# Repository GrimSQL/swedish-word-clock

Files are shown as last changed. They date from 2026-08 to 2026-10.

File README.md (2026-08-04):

# Swedish Word Clock Simulator

An interactive browser-based simulator for a Swedish word clock (QlockTwo-style), designed as a proof-of-concept before building the physical hardware.

**[Live Demo](https://grimsql.github.io/swedish-word-clock/)**

  

## How It Works

The clock displays the current time in Swedish using illuminated words on an 11×10 letter grid. Time is shown in 5-minute intervals with the prefix **KLOCKAN ÄR** ("the clock is"), and four corner dots indicate extra minutes within each interval.

### Swedish Time Logic

Swedish uses a "half-hour" system where times from `:25` onward reference the **next** hour:

| Time  | Display |
|---|---|
| 16:00 | KLOCKAN ÄR **FYRA** |
| 16:05 | **FEM ÖVER** FYRA |
| 16:10 | **TIO ÖVER** FYRA |
| 16:15 | **KVART ÖVER** FYRA |
| 16:20 | **TJUGO ÖVER** FYRA |
| 16:25 | **FEM I HALV** FEM |
| 16:30 | **HALV** FEM |
| 16:35 | **FEM ÖVER HALV** FEM |
| 16:40 | **TJUGO I** FEM |
| 16:45 | **KVART I** FEM |
| 16:50 | **TIO I** FEM |
| 16:55 | **FEM I** FEM |

### Grid Layout

<pre>
<b>K L O C K A N</b> V H <b>Ä R</b>         KLOCKAN ÄR
S <b>F E M</b> I S <b>T I O</b> N A         FEM(min) TIO(min)
<b>T J U G O</b> M I E S N D         TJUGO
<b>K V A R T</b> B <b>Ö V E R</b> G         KVART ÖVER
L <b>I</b> A H <b>H A L V</b> Ö T P         I HALV
<b>E T T</b> R <b>T V Å</b> L S N D         ETT TVÅ
<b>T R E</b> N <b>F Y R A</b> O S T         TRE FYRA
<b>F E M</b> B <b>S E X</b> O <b>S J U</b>         FEM(hour) SEX SJU
<b>Å T T A</b> M <b>N I O</b> D E K         ÅTTA NIO
<b>E L V A T O L V T I O</b>         ELVA TOLV TIO(hour)
</pre>

> `FEM` and `TIO` appear twice each — once as minute words (row 1) and once as hour words (rows 7/9). **Bold** = active letters, normal = filler.

### Corner Dots

Four LEDs in the corners show minutes within each 5-minute block, just like a real QlockTwo:

```
+0 min   ○ ○ ○ ○     (exactly on the 5-min mark)
+1 min   ● ○ ○ ○
+2 min   ● ● ○ ○
+3 min   ● ● ● ○
+4 min   ● ● ● ●
```

## Features

- **6 color themes** — Warm White, Arctic, Matrix, Sunset, Minimal, Rose Gold (saved to localStorage)
- **Time slider** — scrub through the full 24h day to verify every time
- **Direct time input** — type exact times like `16:25` for edge case testing
- **Live mode** — syncs to your system clock in real-time
- **Click to toggle** — click any letter to manually light/dim it (shown in red) for debugging
- **Keyboard shortcuts** — arrow keys (±1 min), `L` (toggle live), `Esc` (close docs)
- **Built-in docs** — click DOCS for full reference on layout, time logic, and hardware specs
- **Single file** — zero dependencies, works offline, just open `index.html`

## Physical Build — `johniak-sv/`

The physical clock is a Swedish remix of [johniak/word-clock](https://github.com/johniak/word-clock) using **this repo's exact 11×10 letter grid** — cross-checked against the simulator's `GRID_LETTERS` on every generation, so the printed front and the simulator can never diverge.

| Component | Details |
|---|---|
| Shell | 3D-printed, 187×179 mm, letters printed in place (AMS: black + transparent) |
| LEDs | 110× WS2812B — **74 LEDs/m strip**, 10 uncut rows of 11 (13.51 mm pitch) |
| Back plate  | 3D-printed: ESP32 bay, self-centring funnel wall hook, alignment pegs, cable channel |
| MCU | ESP32 DevKit v1 (WiFi/NTP), firmware = johniak's + Swedish patch |
| Power | 5V 3A |

Generator, print files (`PRINTA/`), firmware patch and full build guide: [`johniak-sv/README.md`](johniak-sv/README.md).

Earlier build tracks are removed from the tree but remain in git history.

## Credits

The Swedish time-to-word mapping logic is based on [machosallad/tidsram](https://github.com/machosallad/tidsram), the only dedicated Swedish word clock project on GitHub. The 11x10 grid layout was custom-designed for denser packing compared to tidsram's 12x12.

## License

MIT

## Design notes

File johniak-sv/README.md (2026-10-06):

# johniak-sv — svensk version av johniaks Word Clock

Svensk remix av [johniak/word-clock](https://github.com/johniak/word-clock)
(Makerworld: "Word Clock"). Behåller originalets fysiska gränssnitt exakt —
yttermått 187×179 mm, 13,51 mm cellpitch (= 74 LEDs/m-strip), samma serpentin-
LED-ordning — så att originalets monteringsmetod, elektronikbox och firmware-bas
fungerar rakt av. Bara bokstäverna, layouten och tidslogiken är svenska.

**Varför den här basen:** cellavstånd = LED-avstånd → **hela obrutna stripremsor
per rad** (lödning bara vid radslut, ~30 punkter). Bokstäverna fylls med
**transparent filament** (AMS, printed in place) — inga bryggor, riktiga
bokstavsformer, och prime tower ryms gott på en 256-bädd (plattan är 187 bred).

## Layout (11×10 = 110 celler — simulatorns exakta matris)

**Tecken för tecken identisk med simulatorn** (`index.html`), inga tillagda
utfyllnadsbokstäver. Generatorn läser simulatorns `GRID_LETTERS` vid varje
körning och vägrar bygga om en enda cell avviker.

```
K L O C K A N V H Ä R      KLOCKAN ÄR
S F E M I S T I O N A      FEM TIO (minuter)
T J U G O M I E S N D      TJUGO
K V A R T B Ö V E R G      KVART ÖVER
L I A H H A L V Ö T P      I HALV
E T T R T V Å L S N D      ETT TVÅ
T R E N F Y R A O S T      TRE FYRA
F E M B S E X O S J U      FEM SEX SJU
Å T T A M N I O D E K      ÅTTA NIO
E L V A T O L V T I O      ELVA TOLV TIO
```

Valideras dessutom vid varje generering: ordpositioner, alla 288
femminuterstider, läsordning (rad OCH kolumn inom rad), LED-kollisioner.

## Generera

```bash
npm install
node generate.js            # Arial (störst bokstäver). Byt: node generate.js C:\Windows\Fonts\<font>.ttf
```

Utdata:
| Fil | Vad | Filament |
|---|---|---|
| `out/topshell_sv_body.stl` | Front + cellgaller i ett (187×179×12) | SVART (opak) |
| `out/topshell_sv_letters.stl` | Bokstäverna, fyller fronten (2,5 mm djup) | **TRANSPARENT** |
| `out/backplate_sv.stl` | Bakplatta: 12,5 mm ram, ESP32-bay, tratt-krok | SVART |
| `out/backplate_sv_markers.stl` | Strip-markeringsband, 10 st i plattans stripyta | **VIT/kontrast** |
| `out/preview.svg` | Visuell kontroll av layouten | — |
| `out/topshell_walls.svg` | Skalets väggar bakifrån: kabelslitsar + stripurtag | — |
| `firmware/words_sv.h` | Genererad LED-tabell till firmware-patchen | — |

Ingen extern elektronikbox behövs. Bakplattans baksida har en **ram runt hela
kanten, 2 mm bred och 12,5 mm hög** — klockan hänger på den, och lådan den
bildar är elektronikutrymmet. Ramen är 2 mm bred med flit: M3-hålen sitter
4,3–7,7 mm in från kanten, så ett ~6 mm skruvhuvud når 3 mm in — en bredare ram
och huvudet hade inte gått ner bredvid.

I lådan finns **ESP32-bay** (skenor + ändstopp runt en 1,8 mm hög limplatta),
**tratt-krok** som fångar väggskruven själv, **genomföringshål** för LED-kablarna
vid LED 0, och **piggslitsar**: tre piggar på skalets gallerväggar går ner i
slitsarna så plattan självcentrerar — de fyra M3-skruvarna klämmer. Nertill i
ramen är en **13 mm öppning** för USB-C-kontakten (10,5 mm + marginal), full
ramhöjd så kabeln läggs rakt i. Layout: `out/backplate_layout.svg`.

Höjdbudgeten i lådan är knapp och värd att räkna på innan du printar:

| Från plattan | Vad |
|---|---|
| 1,8 mm | limplattans topp |
| 5,0 mm | kortets ovansida (vilar på metallburken/USB-kontakten) |
| 3,4 mm | USB-C-uttagets mitt — därför klarar kontaktens gjutning plattan |
| 6,6 mm | kortets undersida, dit skenorna (7,5 mm) håller det på plats |
| ~12,6 mm | stiftlistens spetsar, om kortet har lödda listar |

Ramen är 12,5 mm. Har ditt kort lödda stiftlistor som sticker ut 6 mm nålar de
alltså precis i väggen — klipp dem korta, eller höj `RIM_H`.

Skalet är i sin tur urfräst för kablaget — allt uppifrån, öppet mot plattan, så
den färdiglödda plattan kan läggas rakt ner utan att något behöver träs igenom:

| Urtag | Var | Mått | Till vad |
|---|---|---|---|
| Stripurtag | topp av **varje** kolumnvägg, en per rad | 11 × 2,2 mm | stripens PCB korsar väggen (LEDsen sitter i cellcentrum, PCB:n pluggar igen urtaget) |
| Kabelslits | de **två yttre** kolumnväggarna, en per rad, båda sidor | 8 × 6 mm | serpentinens 3 ledare (5V/GND/DATA) ut i sidokanalen |
| Matningsslits | vid **LED 0** | 10 × 8 mm | 5 ledare + krympslangsknölen, rakt mot genomföringshålet |

Sidokanalen mellan cellgallret och ytterväggen är 16,2 mm bred och 9,5 mm djup
hela vägen — där ligger looparna. Se `out/topshell_walls.svg`.

## Printa (Bambu Studio)

1. **Top Shell:** importera `topshell_sv_body.stl` + `topshell_sv_letters.stl`
   TILLSAMMANS (svara **Ja** på "single object with multiple parts"). Body →
   filament 1 (svart, opak). Letters → filament 2 (**transparent** PLA — inte vit!).
   Framsidan nedåt. 0.2 mm, inga stöd, brim. Prime tower får plats bredvid.
   > **Obs:** i slicern (uppifrån) läses bokstäverna **baklänges** — det är
   > meningen (samma som originalet). Fronten printas mot plåten, så underifrån/
   > framifrån blir de rättvända. Färgbytena sker bara i de nedersta 2,5 mm.
2. **Bakplatta:** importera `backplate_sv.stl` + `backplate_sv_markers.stl`
   TILLSAMMANS (single object with parts). Plattan → svart, markerings-delen →
   **vit/valfri kontrastfärg** — det blir tio band i första lagret som visar
   exakt var varje LED-rad ska klistras. **Strip-sidan (märkta) nedåt**,
   fickan/kuddarna uppåt. 0.2 mm, brim, inga stöd.
   Utan AMS: skippa marker-filen — banden blir då 0,2 mm försänkta spår istället.

## Montera

1. Klipp 74/m-strippen i **10 hela rader à 11 LEDs** (klipp INTE mellan LEDs i
   raden). Max 10 mm bred strip — piggslitsarna går 0,4 mm från stripkanterna.
2. Klistra raderna **exakt i de tio markerade banden** på plattans stripyta —
   ett band = en rads fotavtryck, inget mätande behövs. **LED 0 (data in) =
   raden närmast genomföringshålet, börja vid hålet**; den raden går bort från
   hålet, serpentin vidare rad för rad.
3. Löd 5V/GND/DIN mellan radsluten. Looparna hamnar utanför gridfältet: de går
   ut genom **kabelslitsen** i den yttre kolumnväggen (8 × 6 mm, en per rad på
   båda sidor) och ligger i sidokanalen mellan cellgallret och ytterväggen.
4. Löd matningen på LED 0 och dra den genom **matningsslitsen** (10 × 8 mm, den
   breda) och vidare ut genom **genomföringshålet** (12 × 10 mm) i plattan strax
   bredvid → till **ESP32-fickan** på baksidan. Där ryms 5 ledare plus knölen
   från krympslangen. 5V + GND till
   strömmen, DIN till GPIO enligt originalets wiring-guide (`docs/device_build.md`).
   ESP32:n läggs i bayen med **metallburken nedåt mot limplattan** och USB-C
   nedåt; superlim på burken. Skenorna tar sidorna, ändstoppet toppen.
5. **Stäng klockan:** lägg plattan på skalet — de tre **piggarna** (sitter
   fast på skalets gallerväggar, printas ihop med skalet) går ner i slitsarna
   (passar bara åt rätt håll) — och skruva **4× M3 självgängande** genom
   plattans hörnhål in i skalets **hörnpelare** (bossarna).
   > Skruvkanalerna i pelarna är **fyrkantiga med flit** (2,7 mm): M3-skruven
   > pressas/gängas rakt i och biter i de fyra plansidorna — fyrkantigt
   > spricker mindre än runt i print. Alternativ: superlimma plattan mot
   > väggtopparna — men först när ALLT är testat (LEDs + firmware); en limmad
   > klocka går inte att öppna för service.
   Strömsladden går från bayen mellan kabelstöden och ut genom ramens
   **USB-öppning** under klockans underkant — kortast möjliga, syns inte framifrån.
6. Häng upp: skruv/spik i väggen med huvudet ~3–4 mm ut. Håll klockan mot väggen ungefär rätt och dra nedåt — **tratt-kroken** fångar skruven, centrerar den själv och låser huvudet bakom läppen. Eller ställ den på bord.
7. Firmware: se [`firmware/PATCH.md`](firmware/PATCH.md).

## Köplista

| Del | Spec |
|---|---|
| WS2812B-strip | **74 LEDs/m**, 2 m (110 LEDs + marginal), 5V, max 10 mm bred |
| ESP32 | DevKit v1 (52 × 28,7 mm — bayen är måttad exakt för den) |
| Superlim | fäster ESP32:ns metallburk mot limplattan |
| Transparent PLA | till bokstäverna (AMS filament 2) |
| Svart PLA | skal + bakplatta |
| Ström | 5V 3A |
| M3 självgängande | 4 st 8–10 mm (bakplatta → skalets bossar) |
| Väggskruv/spik | 1 st, huvud ≤ 9 mm, ~3–4 mm från väggen (tratt-kroken) |

## Äldre byggvarianter

Tidigare byggspår är borttagna ur trädet men finns kvar i git-historiken
(commiten före städningen).

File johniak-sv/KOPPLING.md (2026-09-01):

# Koppling — svensk ordklocka

Praktisk kopplingsplan från oklippt stripprulle till färdig klocka på väggen.
Läs [`README.md`](README.md) för mått och printning, den här filen för elen.

> **Allt som står "vänster" och "höger" i den här filen är sett FRAMIFRÅN**, med
> klockan rättvänd. Bakplattans **stripsida vänder framåt** mot bokstäverna, så
> när du lödar strippen ser du samma bild som någon framför klockan — ingen
> spegling. Först när du vänder plattan för att montera ESP32:n kastas vänster
> och höger om.
>
> Enda entydiga referensen när plattan ligger lös: **USB-C-öppningen i ramen
> sitter i klockans underkant.** Hittar du den vet du var nedan är.

> **Skalet har elva radplatser, men bara tio bär strip.** Den tomma sitter
> **överst**, ovanför KLOCKAN ÄR. Räkna därför aldrig fysiska rader uppifrån —
> utgå från bokstäverna, annars ligger du konsekvent ett steg fel.

---

## Status: vad som redan är gjort

ESP32:n är flashad och konfigurerad. Du behöver inte röra firmware för att koppla.

| | |
|---|---|
| Kort | ESP32-D0WD-V3 rev 3.1, 4 MB flash, MAC `d4:e9:f4:b2:74:20` |
| Firmware | WLED 16.0.1 "Niji" |
| Adress | `192.168.30.17` · `http://ordklocka.local` (fast IP satt i UniFi) |
| Namn | `Ordklockan` |
| LEDs | 110 st, typ WS281x, **GPIO16** |
| Matris | 11 × 10, serpentin, första LED **nere till vänster** |
| Strömgräns | 2000 mA |

Firmware uppdateras härifrån **över OTA** — klockan behöver aldrig mer kopplas
till USB för flashning.

---

## Kopplingsschema

```mermaid
graph LR
    PSU["5V 3A<br/>USB-C-laddare"] -->|USB-C| ESP["ESP32 DevKit v1<br/>i bakplattans bay"]
    ESP -->|"5V"| S5["strip +5V<br/>(röd)"]
    ESP -->|"GND"| SG["strip GND<br/>(vit)"]
    ESP -->|"GPIO16 → 330 Ω"| SD["strip DIN<br/>(grön)"]
```

### Strippens tre kablar → ESP32

**Färgen på pigtailen säger vad kabeln är. Texten på kortet säger vart den ska.**

| Strippens kabel | Signal | ESP32-stift | Står på kortet som |
|---|---|---|---|
| **Röd** | `+5V` | `VIN` | `VIN`, ibland `5V` |
| **Vit** | `GND` | `GND` | ta den **bredvid `VIN`** |
| **Grön** | `DIN` | GPIO16 | **`RX2`**, `D16` eller `16` — alla är samma stift |

Håll kortet med **USB-kontakten nedåt** och komponentsidan mot dig:

- **`VIN`** — nedersta stiftet i **vänstra** raden, hörnet närmast USB
- **`GND`** — direkt **ovanför** `VIN`, samma rad
- **`RX2`** — **högra** raden, **femte stiftet räknat nedifrån**

Röd och vit hamnar alltså bredvid varandra nere till vänster, grön ensam på
andra sidan kortet.

> ⚠️ **Kolla att röd sitter på `VIN` och inte på `RX2` innan du sätter i USB:n.**
> Det är den enda felkopplingen i hela bygget som kan skada kortet — 5 V rakt in
> i en 3,3 V-pinne. Att röd och grön hamnar på var sin sida av kortet är just
> för att göra förväxlingen svår.

Osäker på ditt kort? Mät `VIN` mot `GND` med USB i, ratten på `V⎓`: **4,6–5,0 V**
förväntat. Läser den 0 matar inte det kortet 5 V utåt, och strippens röda får tas
direkt från USB-källan istället.

`GPIO16` är silkscreen-märkt `RX2` på de flesta DevKit v1 — det ser ut som en
seriell port men är rätt stift. Det är satt i WLED under *Config → LED
Preferences*.

### Strippens kabelgrupper

Strippen har två kabelgrupper i samma ände och de sitter parallellt på samma tre
lödöar: en 3-grupp (röd/grön/vit = 5V/DIN/GND) och ett lösare par (röd/vit =
5V/GND för strömmatning). **De 3 är inte RGB** — WS2812B är adresserbar och
styrs av en enda dataledare.

### Verifiera innan du lödar

1. Titta på silkscreen där kablarna sitter: öarna är märkta `+5V`, `DIN`/`DO`, `GND`
2. Kolla pilarna på strippen — **ingångsänden är den pilarna pekar bort ifrån**
3. Den änden ska bli LED 0, alltså raden vid genomföringshålet

---

## LED-ordningen

Serpentin, 10 rader à 11 LEDs. Nedan sett framifrån, rad 1 överst.

| Rad | Bokstäver | LED | Riktning | Skarv till nästa rad |
|---|---|---|---|---|
| 1 | `K L O C K A N V H Ä R` | 99 → 109 | ← höger till vänster | — (sista) |
| 2 | `S F E M I S T I O N A` | 88 → 98 | → vänster till höger | **höger** kant |
| 3 | `T J U G O M I E S N D` | 77 → 87 | ← höger till vänster | **vänster** kant |
| 4 | `K V A R T B Ö V E R G` | 66 → 76 | → vänster till höger | **höger** kant |
| 5 | `L I A H H A L V Ö T P` | 55 → 65 | ← höger till vänster | **vänster** kant |
| 6 | `E T T R T V Å L S N D` | 44 → 54 | → vänster till höger | **höger** kant |
| 7 | `T R E N F Y R A O S T` | 33 → 43 | ← höger till vänster | **vänster** kant |
| 8 | `F E M B S E X O S J U` | 22 → 32 | → vänster till höger | **höger** kant |
| 9 | `Å T T A M N I O D E K` | 11 → 21 | ← höger till vänster | **vänster** kant |
| 10 | `E L V A T O L V T I O` | **0** → 10 | → vänster till höger | **höger** kant |

**Data börjar nederst till vänster** (LED 0 = `E` i ELVA) och slutar överst till
vänster (LED 109 = `K` i KLOCKAN). Nio skarvar totalt: fem på höger kant, fyra
på vänster.

> Källa: `ledIndex()` i [`generate.js:153`](generate.js). Kommentaren på rad 150
> säger "index 0 = bottom-right" — den är ärvd från johniaks 11-radersoriginal
> och stämmer inte här. Med 10 rader blir pariteten omvänd: rad 9 är udda, så
> `index = x` och LED 0 hamnar i kolumn 0. Rad 505 har det rätt.

### Varannan rad roteras 180°

Det här är det lättaste att göra fel. Varje klippt rad har en DIN-ände och en
DOUT-ände, och pilen visar riktningen. Rader som går vänster→höger (10, 8, 6, 4,
2) läggs med pilen åt höger. Rader som går höger→vänster (9, 7, 5, 3, 1) läggs
med pilen åt vänster — alltså **roterade ett halvt varv i planet**.

Rotera i planet, vänd inte på strippen. LEDsen ska fortfarande peka framåt.

> ⚠️ **Att pilarna pekar åt olika håll är RÄTT, inte fel.** Grannrader ska alltid
> peka åt var sitt håll — det är själva serpentinen. Ser du "flera lister åt fel
> håll" är det nästan alltid det här mönstret du tittar på, och då är allt som
> det ska.

| Pilen pekar | Rader |
|---|---|
| **åt höger →** | 10, 8, 6, 4, 2 |
| **åt vänster ←** | 9, 7, 5, 3, 1 |

Ögat är ändå inte facit här. **Stapel-testet är det**: släck allt, tänd den
vänstra LEDen i varje lödd rad (`99`, `88`, `77`, `66`, `55` …) i var sin färg.
De ska bilda en lodrät linje i vänsterkanten. Hoppar en av dem över till
högerkanten ligger just den raden bakvänd — och bara den.

En rad som klarat stapel-testet är bevisad rätt oavsett hur pilen ser ut för
ögat. Löd aldrig om en verifierad rad på en känsla.

---

## Steg för steg

> **Steg 1–2 är redan gjorda** — raderna är klippta och uppklistrade. Markerings-
> banden kom ut något förskjutna i printen; raderna är utmätta och placerade för
> hand istället och sitter rätt. Nästa sak att göra är att kontrollera
> pilriktningen (se nedan) och sen löda.

### 0. Testa hela rullen INNAN du klipper

Oklippt rulle = 148 LEDs. Koppla den provisoriskt med jumperkablar (5V, GND,
GPIO16) och kör igenom den. Hittar du en död LED nu är det en reklamation —
hittar du den efter 30 lödpunkter är det ditt problem.

> ⚠️ **Max 20 % ljusstyrka.** 148 LEDs på full vit drar 8,9 A. USB:n browner ut,
> kortet bootloopar, och det ser ut som trasig hårdvara.

### 1. Klipp 10 rader à 11 LEDs

Klipp **mitt i lödöarna mellan LEDs**, aldrig inne i en LED. Klipp inte inuti en
rad — varje rad ska vara 11 obrutna LEDs.

### 2. Klistra i markeringsbanden

Ett band = en rads fotavtryck, inget mätande behövs. Börja med rad 10 (`ELVA…`)
vid genomföringshålet. Kontrollera pilriktningen mot tabellen ovan **innan** du
trycker fast — 3M-tejpen släpper ogärna snyggt.

Lägg en klick smältlim i varje radände som avlastning. Stripens egen tejp
släpper från PLA efter ett par år i värme.

### 3. Löd de nio skarvarna

Tre ledare per skarv: `5V`, `GND`, `DO → DIN`. Loopen går ut genom
**kabelslitsen** (8 × 6 mm) i den yttre kolumnväggen och ligger i sidokanalen
mellan cellgallret och ytterväggen (16,2 mm bred, 9,5 mm djup).

- 24 AWG silikonkabel, ~6 cm per ledare
- Förtenna både ö och tråd, sen bara nudda ihop
- Krympslang över varje skarv
- Blyfritt: 350–370 °C, flussmedel är obligatoriskt, fogen blir matt och kornig — det är normalt

#### Skarvschemat

Kanten växlar varje gång. Datan går nedifrån och upp, så skarv 1 är den nedersta.

| Skarv | Från → till | Kant | Testa efter, 2D-index | Tända LEDs |
|---|---|---|---|---|
| 1 | rad 10 → 9 | **höger** | `[88,110,"FFFFFF"]` | 22 |
| 2 | rad 9 → 8 | **vänster** | `[77,110,"FFFFFF"]` | 33 |
| 3 | rad 8 → 7 | **höger** | `[66,110,"FFFFFF"]` | 44 |
| 4 | rad 7 → 6 | **vänster** | `[55,110,"FFFFFF"]` | 55 |
| 5 | rad 6 → 5 | **höger** | `[44,110,"FFFFFF"]` | 66 |
| 6 | rad 5 → 4 | **vänster** | `[33,110,"FFFFFF"]` | 77 |
| 7 | rad 4 → 3 | **höger** | `[22,110,"FFFFFF"]` | 88 |
| 8 | rad 3 → 2 | **vänster** | `[11,110,"FFFFFF"]` | 99 |
| 9 | rad 2 → 1 | **höger** | `[0,110,"FFFFFF"]` | 110 |

Fem på höger kant, fyra på vänster. Varje rad ligger vänd 180° mot sin granne, så
vid varje skarv gäller: **ström korsar diagonalt, data rakt över mitten.** Mitten-
ön är data på båda raderna och är den enda som inte byter sida vid rotationen.

#### Kolla riktningen på varje ny rad

Att raden lyser räcker inte — den kan lysa och ändå ligga bakvänd. Släck allt och
tänd den vänstra LEDen i varje lödd rad, en färg per rad:

```powershell
wled '{"on":true,"bri":128,"seg":[{"id":0,"fx":0,"frz":false,"col":[[0,0,0]]}]}'
wled '{"seg":[{"i":[99,"FF0000"]}]}'
wled '{"seg":[{"i":[88,"0000FF"]}]}'
wled '{"seg":[{"i":[77,"00FF00"]}]}'
```

De ska bilda en **lodrät linje i vänsterkanten**, en per rad nedifrån och upp.
Hoppar en av dem över till högerkanten ligger den raden 180° fel — och då ska
tejpen lossna nu, inte efter nästa skarv. Fortsätt med nästa index ur tabellen
(`66`, `55`, `44` …) allteftersom du lödar uppåt.

#### Mät varje skarv innan du sätter ström

Trettio sekunder med multimeter per skarv. Det är skillnaden mellan att **veta**
vilken fog som är trasig och att gissa i en färdiglödd loop.

Svart mätsladd i `COM`, röd i `VΩmA` — aldrig i `10A`-hålet, då kortsluter du det
du mäter så fort du går över till spänningsläge.

**Kontrollera mätaren på sig själv först:** nudda ihop de två metallspetsarna, den
ska pipa. Utan det vet du inte om "inget pip" betyder *ingen brygga* eller *fel
ratt-läge*.

**Grundregeln, och den enda du behöver minnas:**

| Du mäter | Pip betyder |
|---|---|
| **Längs samma ledare** — två ändar av samma tråd, eller `+5V`-ö till `+5V`-ö | ✅ Bra, strömmen kommer fram |
| **Mellan två olika ledare** — `+5V` mot `GND`, data mot `+5V` | ❌ Brygga |

Två avläsningsfällor: **`1` eller `OL` ensamt** längst till vänster betyder *över
mätområdet*, alltså **ingen** förbindelse — inte 1 ohm. Och ett **tal utan pip**
(t.ex. 718 Ω) mellan data och `GND` är LEDens inbyggda skydd, helt normalt. Det
är pipet som betyder brygga.

**1. Kortslutning mellan `+5V` och `GND`.** USB **ur** kortet — resistansmätning
på en strömsatt krets ger skräpvärden och kan skada mätaren. Ratten på `Ω` eller
kontinuitet ( ))) ). Proberna på `+5V`- och `GND`-ön i den nylödda radens ände.

| Du ser | Betyder |
|---|---|
| Några hundra Ω till flera kΩ, siffran **kryper uppåt** | Bra — LEDsens kondensatorer laddas av mätarens testström |
| Kort pip som tystnar | Samma sak. Normalt |
| **0–2 Ω, eller pip som inte slutar** | Brygga. Ta bort med avlödningsflätan och mät om innan ström |

**2. Att skarven sitter ihop.** Fortfarande strömlöst, kontinuitetsläge. Mät
tvärs över skarven, ö till ö: `DO → DIN`, `+5V → +5V`, `GND → GND`. Alla tre ska
pipa. Piper det inte är fogen kall — det felet kostar annars tio minuters
felsökning efter att du satt på strömmen.

**3. Spänningen från `VIN`.** Nu med USB i. Ratten på `V⎓` (DCV, inte vågen).
Svart på `GND`, röd på `VIN`. Förväntat **4,6–5,0 V**. Läser den 0 matar inte det
kortet 5 V utåt, och strippens röda får tas direkt från USB-källan istället.

Rutinen för resten av bygget: **löd skarv → mät 1 → mät 2 → USB i → tänd.**

### 4. Matningen på LED 0

Löd 5V, GND och DIN på LED 0:s öar (eller behåll fabrikskontakten om du klippt
så att ingångsänden hamnar där — då är den redan gjord). Sätt **330 Ω i serie på
DIN här**, inte vid ESP32:n.

Dra kabeln genom **matningsslitsen** (10 × 8 mm, den breda) och vidare ut genom
**genomföringshålet** (12 × 10 mm) i plattan → till ESP32-fickan på baksidan.

### 5. Testa alla 110 — innan något skruvas ihop

Koppla till ESP32:n med jumperkablar, stiften fortfarande hela. Kör
testkommandona nedan. Det här är sista tillfället att komma åt allt.

**Testa en rad i taget, inte allt på slutet.** Löd en skarv, tänd allt som är
lött, gå vidare. Startindex ur tabellen i [Testkommandon](#index-per-rad).
Tumregeln: lyser allt utom från skarv N och uppåt sitter felet i skarv N, och
ingen annanstans. Nio skarvar, nio tester — det är billigare än att leta i en
färdiglödd loop.

### 6. Löd fast på ESP32

Först nu, när testet är grönt:

1. Klipp stiften till **2–3 mm stubbar** (alla, inte bara de tre — resten nålar annars i väggen). Skyddsglasögon, de flyger
2. Löd kablarna på stubbarna
3. Klick smältlim som dragavlastning

Höjdbudgeten: ramen är 12,5 mm och ohyvlade stift når 12,6 mm. Dupont-hus ovanpå
är omöjliga — de skulle hålla klockan ut från väggen. Vill du ha en kontakt:
löd 3 cm pigtails på kortet och sätt en **JST-SM 3-pol wire-to-wire** liggande
platt i lådan (~6 mm tjock), eller höj `RIM_H` i [`generate.js:219`](generate.js) och printa om.

### 7. Montera

1. ESP32 i bayen, **metallburken ner** mot limplattan, USB-C nedåt. Superlim på burken
2. Lägg plattan på skalet — de tre piggarna går ner i slitsarna, passar bara åt rätt håll
3. 4× M3 självgängande genom hörnhålen in i skalets bossar
4. Strömsladden mellan kabelstöden och ut genom ramens USB-öppning
5. Häng på tratt-kroken: skruv i väggen med huvudet 3–4 mm ut, håll klockan mot väggen och dra nedåt

---

## Testkommandon

> ⚠️ **`i` räknar i matrisens läsordning, inte i datakedjan.** WLED körs i 2D-läge
> (11 × 10), och där är index **0 = övre vänstra hörnet** (`K` i KLOCKAN). Fysisk
> LED 0 — `E` i ELVA, nere till vänster — är alltså **2D-index 99**.
>
> `i` måste dessutom skickas **ensamt i sitt eget anrop**. Skickar du `col` eller
> `frz` i samma request händer ingenting synligt: segmentet fryser med föregående
> bild kvar och `i` faller bort. Sätt bakgrunden i ett anrop, tänd i nästa.
>
> Verifierat mot enheten 2026-08-30, under lödningen av rad 10.

### Index per rad

Startindex sjunker med 11 för varje rad du lödar på. Stopp är alltid 110.

| Rader lödda | Fysiska LEDs | Tänd 2D-index |
|---|---|---|
| 1 (`ELVA…`) | 0–10 | `[99,110,…]` |
| 2 (+ `ÅTTA…`) | 0–21 | `[88,110,…]` |
| 3 | 0–32 | `[77,110,…]` |
| 4 | 0–43 | `[66,110,…]` |
| 5 | 0–54 | `[55,110,…]` |
| 6 | 0–65 | `[44,110,…]` |
| 7 | 0–76 | `[33,110,…]` |
| 8 | 0–87 | `[22,110,…]` |
| 9 | 0–98 | `[11,110,…]` |
| 10 (allt) | 0–109 | `[0,110,…]` |

**start = 110 − 11 × antal rader.**

### PowerShell

`curl` är ett alias för `Invoke-WebRequest` i PowerShell, och PS 5.1 äter dessutom
citattecknen i JSON:en innan riktiga `curl.exe` hinner se dem. Definiera en
hjälpare istället — en gång per terminalfönster:

```powershell
function wled($json) { Invoke-RestMethod -Uri http://192.168.30.17/json/state -Method Post -ContentType 'application/json' -Body $json }
```

**Svart bakgrund** (ofryst) — kör alltid detta först, annars ligger gammal bild kvar:

```powershell
wled '{"on":true,"bri":128,"seg":[{"id":0,"fx":0,"frz":false,"col":[[0,0,0]]}]}'
```

**Tänd bara fysisk LED 0 rött** — ska lysa nere till vänster, `E` i ELVA:

```powershell
wled '{"seg":[{"i":[99,"FF0000"]}]}'
```

**Riktningstest** — ska växa åt höger, `E L V`:

```powershell
wled '{"seg":[{"i":[99,102,"FF0000"]}]}'
```

**Tänd alla lödda rader vitt** — leta mörka luckor. Byt 99 mot startindex ur
tabellen ovan allteftersom du lödar uppåt:

```powershell
wled '{"seg":[{"i":[99,110,"FFFFFF"]}]}'
```

**Tillbaka till normalt läge.** Individuell LED-styrning fryser segmentet — utan
det här kör inga effekter:

```powershell
wled '{"on":true,"bri":128,"seg":[{"id":0,"fx":0,"frz":false,"col":[[255,160,0]]}]}'
```

**Läs av kortets faktiska tillstånd** när något beter sig oväntat:

```powershell
Invoke-RestMethod http://192.168.30.17/json/state
```

**Släck:**

```powershell
wled '{"on":false}'
```

### bash / curl

Samma anrop, för den som sitter på en Linux-burk:

```bash
curl -X POST -H "Content-Type: application/json" -d '{"on":true,"bri":128,"seg":[{"id":0,"fx":0,"frz":false,"col":[[0,0,0]]}]}' http://192.168.30.17/json/state
```

```bash
curl -X POST -H "Content-Type: application/json" -d '{"seg":[{"i":[99,"FF0000"]}]}' http://192.168.30.17/json/state
```

```bash
curl -X POST -H "Content-Type: application/json" -d '{"seg":[{"i":[99,110,"FFFFFF"]}]}' http://192.168.30.17/json/state
```

```bash
curl -X POST -H "Content-Type: application/json" -d '{"on":true,"bri":128,"seg":[{"id":0,"fx":0,"frz":false,"col":[[255,160,0]]}]}' http://192.168.30.17/json/state
```

## Felsökning

| Symptom | Trolig orsak |
|---|---|
| Ingenting lyser alls | Ingen gemensam GND, eller DIN i fel ände av strippen (kolla pilarna) |
| `i`-kommandot gör ingenting, gammal bild ligger kvar | `i` skickades tillsammans med `col`/`frz`. Skicka det ensamt, i eget anrop |
| `i` tänder inget alls, oavsett index | Fel index — 2D-läge räknar i läsordning, fysisk LED 0 = index **99** |
| Allt svart och `{"on":true}` hjälper inte | Primärfärgen står på `[[0,0,0]]`. Sätt en riktig färg i `col` igen |
| Första LED lyser, resten mörka | Bruten dataledare i första skarven, eller DO/DIN förväxlade |
| Allt lyser men fel LEDs tänds | Rad lagd åt fel håll — jämför mot riktningskolumnen i tabellen |
| Hela bilden speglad | Fel `b`/`r` i WLED:s 2D-panel. Fixas i mjukvara, inte med lödkolven: *Config → 2D Configuration → First LED* |
| Slumpmässigt flimmer | 3,3 V data mot 5 V-strip. Testa kortare datakabel först, annars 74AHCT125 som nivåomvandlare |
| Kortet startar om vid hög ljusstyrka | Strömbrist. Kolla att gränsen är 2000 mA under *Config → LED Preferences* |
| Ojämn ljusstyrka över raderna | Spänningsfall. Bara relevant om du kör över 2 A — annars är 24 AWG gott och väl |

Orientering är alltid en mjukvaruinställning. Har du lödt rätt serpentin men
bilden hamnar fel — rör inte lödkolven, vänd `b`/`r`/`v` i 2D-konfigurationen.

---

## Vad som återstår efter det här

Standard-WLED visar **inte** svensk tid. Det du får nu är alla 110 LEDs,
2D-effekter och HA-integration. Klockfunktionen kräver den custom-byggda word
clock-usermoden — steg 3 i [`../TODO.md`](../TODO.md).

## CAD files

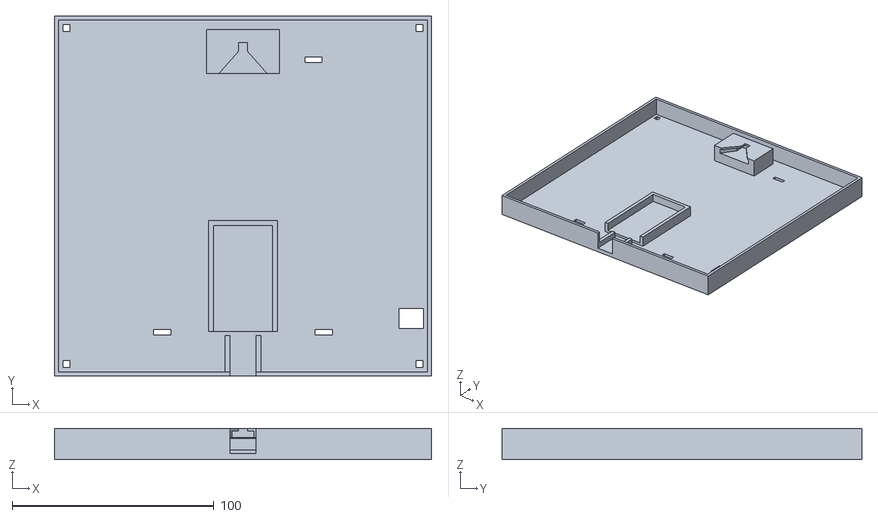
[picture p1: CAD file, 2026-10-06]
johniak-sv/PRINTA/3_bakplatta-SVART.stl
187.1 x 178.6 x 15.5

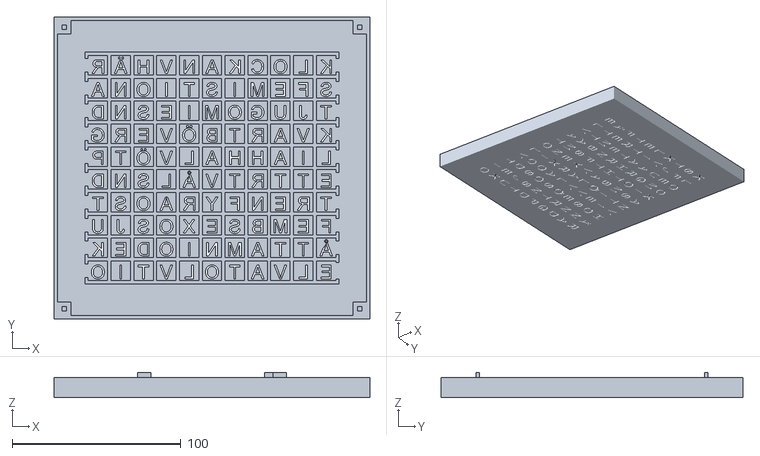
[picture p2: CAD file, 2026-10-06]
johniak-sv/PRINTA/1_topshell-SVART.stl
187.1 x 178.6 x 15.0

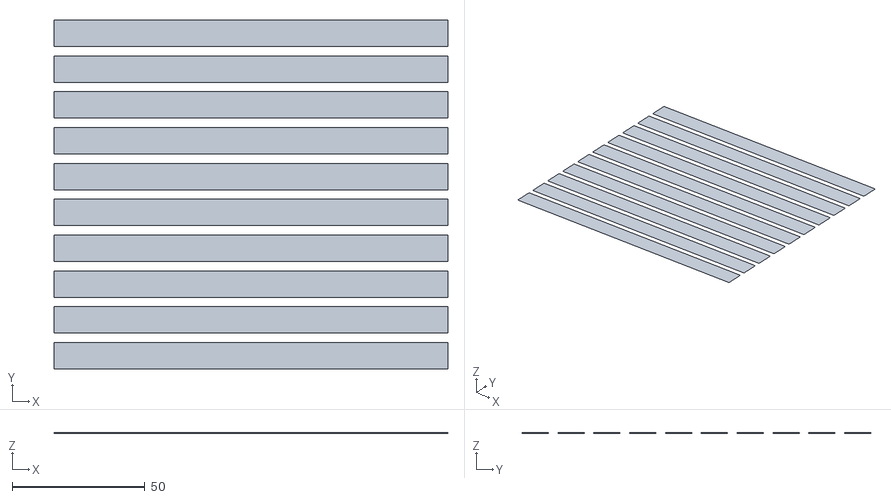
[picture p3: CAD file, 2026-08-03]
johniak-sv/PRINTA/4_bakplatta-markeringar-VIT.stl
148.6 x 131.6 x 0.2

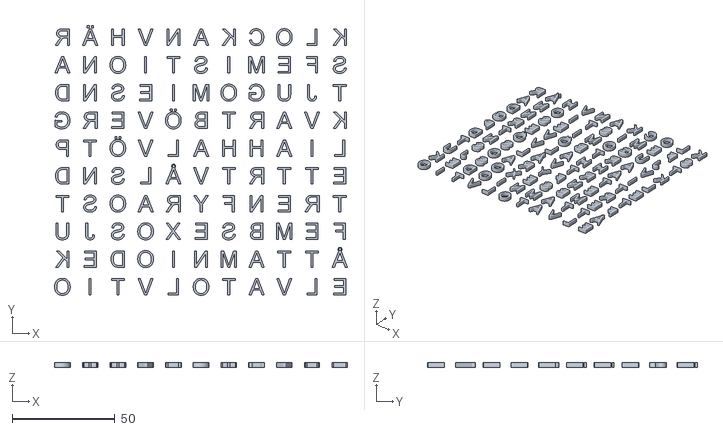
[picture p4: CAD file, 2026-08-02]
johniak-sv/PRINTA/2_topshell-bokstaver-TRANSPARENT.stl
142.8 x 131.4 x 2.50

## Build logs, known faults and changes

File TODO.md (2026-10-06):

# TODO — Svensk ordklocka

Ordningen är medveten: bygg grunden först, sen mjukvarulyxen. Från steg 2 och
framåt rörs aldrig hårdvaran igen — allt är firmware/HA (OTA efter första flashen).

**Status 2026-09-02: klockan hänger på väggen och visar svensk tid.** Steg 1, 3
och det mesta av 4–5 är klara. Kvar är automationerna och simulatorkortet.

## 1. Färdigställ bygget ✅
- [x] Top Shell printad (svart + transparenta bokstäver, AMS)
- [x] Bakplatta v2: piggslitsar fixade, stripband, ficka nere, tratt-krok
- [x] Printa om Top Shell (`johniak-sv/PRINTA/1_` + `2_`) — kabelslitsar per rad,
      bred matningsslits vid LED 0, stripurtag i kolumnväggarna
- [x] Printa om bakplattan (`johniak-sv/PRINTA/3_` + `4_`) — 12,5 mm ram,
      13 mm USB-C-öppning, ESP32-bay med limplatta och krok
- [x] Vänta in leverans: WS2812B 74/m 2 m + ESP32 DevKit v1
- [x] Klipp 10 rader à 11 LEDs, klistra i banden, löd serpentin
- [x] Testa alla 110 LEDs INNAN plattan skruvas fast
- [x] ESP32 i fickan, skruva M3 i hörnpelarna
- [x] Häng på tratt-kroken

> Nio skarvar, alla mätta och verifierade rad för rad. Rutinen och fällorna
> ligger i [`johniak-sv/KOPPLING.md`](johniak-sv/KOPPLING.md) — särskilt att ett
> kontinuitetspip inte räcker på strömledare (en fog på 80 Ω piper glatt och
> stryper ändå raden) och att pilarna ska växla varannan rad.

## 2. Firmware steg 1 — johniak + svensk patch ⏭️ ÖVERHOPPAT
Medvetet hoppat över. Kortet kom med WLED, och steg 3 hade ändå ersatt den här
firmwaren. [`PATCH.md`](johniak-sv/firmware/PATCH.md) sparas som referens —
tidslogiken där är samma som usermoden använder.

## 3. Firmware steg 2 — WLED med svensk word clock-usermod ✅
- [x] Custom-bygg av WLED 16.0.1 med egen usermod
- [x] Porta svenska ordtabellen till usermodens layout (rad/kolumn, inte LED-index)
- [x] Konfigurera 2D-matris 11×10, serpentin, första LED nere till vänster
- [x] Kuratera 17 presets — 5 klocklägen, 5 figurer, 7 helmatriseffekter
- [x] Figurlägen: hjärta, stjärna, gran, snöflinga, katt, blixt, utropstecken
- [x] Sifferdisplay — timer, temperatur och nedräkning är samma tvåsiffriga läge
- [x] `script.ordklockan_timer`, `script.ordklockan_visa_sensor` och
      automationen som håller talet färskt
- [x] Exponera aktuell fras och tänd-mask i `/json/info` för Home Assistant
- [x] OTA-flasha
- [x] NTP + tidszon CET/CEST med automatisk sommartid
- [x] Boot-preset `Klockläge` — klockan kommer tillbaka likadan efter strömavbrott
- [x] Lokal NTP-källa: NAS:en (`192.168.1.30`, DSM:s NTP-server). Krävde en ny
      brandväggsregel `AUTO IoT till NAS NTP` i GrimSQL/udm-firewall — UDM:en kör
      ingen egen NTP-server, verifierat med SNTP-probe mot alla tre VLAN

Källkod och byggguide: [`johniak-sv/firmware/wled-usermod/`](johniak-sv/firmware/wled-usermod/README.md).
Presets skapas om med [`johniak-sv/tools/presets.py`](johniak-sv/tools/presets.py).

## 4. Home Assistant-integration
- [x] WLED-integrationen → `light.ordklockan` + 17 entiteter till
- [x] `packages/ordklockan.yaml`: rest_command för klockläget, `sensor.ordklockan_text`
      (aktuell fras), `binary_sensor.ordklockan_klocklage`
- [x] `script.ordklockan_scen` — sätter preset OCH klockläge i ett anrop
- [x] `input_boolean.ordklockan_manuell` — manuell styrning vinner alltid över
      automationerna. Kortets knappar går via script som tänder flaggan;
      automationerna anropar tjänsterna direkt och rör den aldrig
- [x] Automation: släck när huset larmas **borta** (skalskydd undantaget — då är
      någon hemma). Nollställer också flaggan, så hemkomsten börjar rent
- [x] Automation: Lugn kväll efter solnedgången, Klockläge i dagsljus
- [x] Automation: släpp manuell styrning kl 04 som säkerhetsnät
- [x] Automation: rätta tiden om den glidit. WLED:s `Toki::millisecond()`
      räknade upp sekunder utan lås trots att den anropas från både
      Arduino-loopen och AsyncTCP-tasken — en tappad uppdatering flyttade
      klockan exakt 49 dygn 17:02:47 framåt, två gånger natten till 3 sep 2026.
      Firmwaren är patchad (`toki-threadsafe.patch`), automationen är nätet
      under: enheten NTP-synkar bara var 11,7:e timme
- [ ] Automationer kvar: larmblink (röd puls vid utlöst larm), hemkomst-puls,
      tvätt-klar. Alla tre vill ha en **figur** nu när klockan kan visa ❗ och ✓,
      inte bara en färg

## 5. Lovelace-dashboard
- [x] Effektväljare som knappgrid, scenknappar (Klockläge / Party / Lugn kväll / Natt),
      ljusstyrka, palett, hastighet — i `lampor`-vyn, Viktors button-card-stil
- [x] Simulatorn som live-kort — ritar firmwarens **egen** mask (`u.OrdklockanRutnat`,
      110 tecken i läsordning) via `sensor.ordklockan_rutnat`. Kortet duplicerar
      alltså ingen ordtabell i JavaScript och kan inte säga emot väggen
- [x] Kortet speglar väggens **faktiska pixlar** via `/json/live`
      (`sensor.ordklockan_pixlar`, 110 färger i attributet `leds`, en pollning
      per sekund). Masken räckte inte: den säger vad usermoden ritar, inte vad
      väggen lyser med. I läge `av` maskerar usermoden ingenting och publicerar
      en helt tänd mask — masken sa 110 tända celler medan Eld i verkligheten
      tände 53. Elva av sjutton presets kör en effekt och gick inte att återge
      med mask + en färg. Noteringen ovan om att kortet "inte kan säga emot
      väggen" gällde bokstäverna, inte ljuset
- [x] Knapparnas accentfärg följer väggens färg i stället för fast bärnsten,
      med läsbarhetsvakt för ljust tema
- [ ] Automations-togglar + ev. plats på floorplanen
- [ ] WLED:s webb-UI som iframe-flik för finlir

## Lösa trådar
- **330 Ω på datalinjen** är medvetet överhoppad. Klockan har gått felfritt utan
  den; är den första åtgärden om flimmer dyker upp.
- **`ordtest.py` mot `--all`** har aldrig körts hela varvet med plattan på.
  Värt att göra en gång för att se alla tolv femminutersblock.
- **WLED backar av 5 minuter** efter varje misslyckad NTP-uppslagning. Testa
  alltid NTP-ändringar med en omstart — annars mäter du backoffen och drar fel
  slutsats om nätverket.

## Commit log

2026-02-14 Initial release: Swedish word clock simulator
    Single-file HTML/JS simulator for a QlockTwo-style Swedish word clock.
    11x10 grid layout (110 LEDs + 4 corner dots), 6 color themes,
    time slider, live mode, and built-in documentation.
2026-02-14 Add laser cutting files: SVG generator, three grid sizes, stencil, separator and ordering guide
    Parametric Node.js generator produces laser-ready SVGs for the word clock front panel
    in S/M/L sizes, a stencil variant with Allerta Stencil font, and an egg-crate separator
    grid. Includes Swedish ordering guide with EU laser cutting services.
2026-02-14 Fix ÅÄÖ in README and add DXF export for Scandcut
    - Replace all ASCII approximations (AR→ÄR, OVER→ÖVER, TVA→TVÅ, ATTA→ÅTTA)
    in README grid layout and time examples
    - Add DXF R12 generator for CAD-compatible output
    - Generate wordclock-grid-L.dxf for Scandcut (32KB, within 10MB limit)
    - Update BESTALLNING.md with Scandcut-specific instructions
    [wordclock-grid-L.dxf]
2026-02-14 Remove text entities from DXF to fix Scandcut upload error
    Their system rejects TEXT entities due to missing fonts. The DXF now
    contains only cut geometry (rectangles, circles) — no text/engrave layer.
    Letter labels remain in the SVG files for reference.
    [wordclock-grid-L.dxf]
2026-02-14 Add stencil DXF with vector letter outlines for Scandcut
    - Generate stencil variant in L size (525×480mm) instead of M
    - Use Inkscape CLI to convert Allerta Stencil text → vector paths → DXF
    - DXF contains 250 polylines, zero text entities — no font errors
    - Remove old wordclock-stencil-M.svg
    [wordclock-stencil-L.dxf]
2026-02-14 Change filler letters between KLOCKAN and ÄR from DA to VH
    Easter egg: the two non-illuminated letters in row 0 positions 7-8
    are now V and H (builder's initials). Updated in index.html, generator,
    README grid layout, and all generated SVG/DXF files.
    [wordclock-stencil-L.dxf]
2026-02-14 Format grid layout with bold active letters and all uppercase
    All letters are now consistently uppercase. Active word letters are
    bold, filler letters are plain — replaces the old lowercase/uppercase
    convention that was inconsistent.
2026-02-14 Add 3D-printable backplate grid in 9 sections
    Node.js generator creates STL files for a cell grid that prevents LED
    light bleed. Split into 3x3 sections (max 183mm) for standard print beds.
    Features: 3mm walls, 20mm cell depth, 4x5mm wire notches between cells,
    LED guide rings, and interlocking tabs for assembly.
    [backplate_section_0_0.stl, backplate_section_0_1.stl, backplate_section_0_2.stl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]
2026-02-14 Switch from stencil font to Arial Bold for full letter cutouts
    Removes stencil bridges — letters like A, O, Ö, Å, D, B, P, R are now
    complete shapes. Inner pieces fall out during cutting and are glued onto
    the diffuser sheet for a cleaner look.
    [wordclock-stencil-L.dxf]
2026-02-14 Revert to Allerta Stencil font with proper stencil bridges
    Bridges keep inner pieces of A, O, Ö, Å, D, B, P, R attached during
    laser cutting. No floating pieces that could fall out.
    [wordclock-stencil-L.dxf]
2026-02-14 Change filler letters in row 4 from DK to AH
    Easter egg: positions 46-47 between I and HALV now spell AH
    (Annica Härlin & Alva Härlin). Updated in simulator, generator,
    README, and all generated SVG/DXF files.
    [wordclock-stencil-L.dxf]
2026-02-14 Add 3D-printable test front panel in 9 sections
    Grid variant with 37mm square cell windows for testing fitment,
    LED alignment, and light distribution before ordering laser-cut metal.
    3mm thick, black PLA, 100% infill. Same section split as backplate.
    [frontplate_test_0_0.stl, frontplate_test_0_1.stl, frontplate_test_0_2.stl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]
2026-02-14 Add password authentication with PBKDF2 hashing
    - First-run setup GUI to create password
    - Login screen on subsequent visits
    - Change password and logout buttons in main UI
    - Requirements: 20+ chars, uppercase, lowercase, digit, special char
    - PBKDF2 with 100k iterations via Web Crypto API
    - Session persists per browser tab, password hash in localStorage
2026-08-02 Add mini 3D-print track and johniak-sv Swedish remix
    Mini track (18mm pitch, single-piece parts for a 256mm bed): parameterized
    generators, stencil/2-colour/window front variants, two-part back, print
    package under laser/PRINTA-MINI.
    johniak-sv: Swedish remix of johniak word-clock — simulator-exact 11x10 grid
    (cross-checked against index.html on every generation), 13.51mm pitch for
    uncut 74 LED/m strip rows, mirrored in-place AMS letters, back plate with
    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
    [1_cellgaller-SVART.stl, 1_topshell-SVART.stl, 2_bakstycke-SVART.stl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]
2026-08-02 Remove superseded build tracks; johniak-sv is the build
    Delete the laser/ directory entirely: laser-cut S/M/L faceplate files, the
    3x3-tiled L-size 3D-print sections, the 18mm mini variants (stencil, 2-colour
    and window fronts, two-part back, PRINTA-MINI package) and their generators
    and build guides. All of it remains available in git history.
    The repo now holds the simulator (index.html) and the physical build under
    johniak-sv/. README rewritten accordingly.
    [1_cellgaller-SVART.stl, 2_bakstycke-SVART.stl, 3_front-stencil-SVART.stl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]
2026-08-02 Remove leaked laser node_modules and scrub laser references
    The cleanup commit deleted laser/frontplate-2color/.gitignore in the same
    sweep as the directory, which let git add -A stage the node_modules that the
    ignore file had been guarding. Remove them, drop the remaining laser mentions
    from both READMEs, and rewrite johniak-sv/.gitignore without a UTF-8 BOM so
    its node_modules/ rule actually matches.
2026-08-03 Fix back plate peg slots to match the as-printed shell; add strip markers
    The shell emits walls and pegs through an X-only mirror while plate holes go
    through an X+Y mirror, so the three peg slots landed vertically mirrored and
    the printed parts could not mate. Pre-flip the slot Y to target the pegs
    where they actually sit on the printed shell (verified against the shell STL:
    all three pegs land inside their slots with 0.3mm clearance). The shell mesh
    is untouched — only the plate needs reprinting.
    Also add backplate_sv_markers.stl: ten 10mm first-layer bands in a contrast
    filament marking exactly where each LED strip row is glued (0.2mm recessed
    grooves when printed without AMS).
    [3_bakplatta-SVART.stl, 4_bakplatta-markeringar-VIT.stl]
2026-08-03 Clarify assembly: corner bosses take the M3 screws, square pilots by design
    The four corner pillars in the shell are screw bosses, not loose parts: M3
    self-tappers go through the plate corner holes straight into their square
    2.7mm pilot channels (square cracks less than round in printed PLA and gives
    displaced material somewhere to go). Note gluing as an alternative with a
    service warning. Drop the loose-pegs spare file added moments earlier — the
    shell-mounted pegs plus screws cover everything.
2026-08-04 Move ESP32 bay to the hanging bottom of the back plate
    The bay sat in the upper half of the back, forcing the power cable up and
    over the top edge. Flip it: bay at the hung bottom with the USB opening
    toward the bottom edge and short guide stubs below, so the cable drops
    straight out under the clock. Also puts the bay closer to the LED wire
    pass-through. Redraw backplate_layout.svg in true hanging orientation
    (the old one mixed coordinate frames and misplaced the bay).
    [3_bakplatta-SVART.stl]
2026-08-04 Replace flat keyhole with a self-centring funnel wall hook
    The keyhole through-hole required blindly hitting a 9mm opening on an
    invisible screw. The new hanger is a solid boss on the back at the hung top:
    a 24mm V-funnel opens downward, catches the screw or nail anywhere within
    its width while sliding the clock down, self-centres the shaft into the
    slot and locks the head in a cavity behind a 1.4mm face lip. Flush with
    the standoff pads so the clock hangs flat, and the plate no longer has a
    hole at the top. Built from polygon prisms via a new addBackPrism helper
    in the back-feature frame.
    [3_bakplatta-SVART.stl]
2026-08-30 Add wiring guide with verified 2D LED indexing and multimeter checks
    KOPPLING.md was written assuming a 1D strip, so its test commands never
    worked against the device: WLED runs an 11x10 matrix, where the JSON `i`
    array addresses matrix reading order, not the data chain. Physical LED 0
    (E in ELVA, bottom left) is index 99, not 0. `i` must also be sent alone
    in its own request -- combined with `col`/`frz` the segment freezes on
    the previous frame and the write is dropped.
    Both behaviours confirmed on the device while soldering row 10.
    - Correct indices plus a per-row table (start = 110 - 11 * rows soldered)
    - PowerShell variants; `curl` is an Invoke-WebRequest alias and PS 5.1
    eats the JS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
2026-09-01 Document exact ESP32 pins and the multimeter continuity rule
    The wiring table said "GPIO16" without mentioning that DevKit v1 silkscreens
    it as RX2, so the pin was hard to find on the board. Names the labels, the
    physical positions, and calls out red-on-RX2 as the one miswiring that can
    damage the board.
    Also adds the rule that kept tripping us up during row 9 and 10: a beep
    along one conductor is good, a beep between two conductors is a bridge --
    plus the two display traps (OL/1 means open, and a number without a beep
    between data and GND is the LED's internal protection).
2026-09-01 Add splice schedule table and per-row direction check to step 3
    Which edge a splice sits on and which index range to light afterwards had
    to be derived from two separate tables each time. Collapses both into one
    nine-row schedule next to the soldering instructions, where it is actually
    read.
    Also documents the stacked-LED direction check: lighting the leftmost LED
    of each soldered row should draw a vertical line up the left edge. A row
    lit the wrong way round still lights, so "it works" is not enough on its
    own -- and the tape is far easier to lift before the next splice.
2026-09-01 Warn that alternating strip arrows are correct, not a fault
    Neighbouring rows must point opposite ways -- that is the serpentine. Seen
    across a half-built plate it reads as "several strips are backwards", which
    invites reworking rows that are already verified.
    Names which rows point which way, and makes explicit that the stacked-LED
    test is the authority: a row that passed it is proven correct regardless of
    how the arrow looks, and must not be resoldered on a hunch.
2026-09-02 Add WLED word clock usermod, verification tools and HA integration
    The clock now runs a custom WLED 16.0.1 build that shows Swedish time in
    words, driven from Home Assistant. This lands the source that only existed
    on the device and in an out-of-tree WLED clone.
    firmware/wled-usermod/
    The usermod itself. It only blanks the LEDs outside the current time, so
    every WLED 2D effect still paints the letters. Two findings are recorded
    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
2026-09-02 Record boot preset and the local NTP source
    The clock now applies preset 1 at boot and takes its time from the NAS
    instead of a public pool, so a power cut during a WAN outage no longer
    leaves it dark. Both were verified by reboot, not by assumption.
    Also notes WLED's five-minute NTP backoff under loose ends -- it is the
    reason a working IoT DNS was misdiagnosed as broken earlier, and it will
    mislead the next person to touch NTP settings here.
2026-09-02 Add heart and star shapes as display modes
    Viktor wanted a heart, then a star. Rather than bolt a second boolean next
    to the word-clock flag -- where "clock on" and "heart on" could both be true
    and fight over the same mask -- the usermod now carries a single mode:
    klocka / hjarta / stjarna / av. Two flags can conflict; one field cannot.
    The shapes are ASCII bitmaps in the source, one string per matrix row, so a
    new figure is ten lines of text with no indices to compute and the shape is
    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
2026-09-02 Count seconds until they no longer fit, not until a minute
    Pressing "99 sekunder" showed 2. The rule switched to minutes above 60s, so
    99 became ceil(99/60) = 2 -- correct by the rule, wrong by the label, and
    wrong by what a countdown from 99 is for.
    The threshold belongs at 99, not 60: show the most precise unit that fits in
    two digits. A five-minute timer now reads 5, 4, 3, 2 and then switches to
    seconds at 99 and counts down to zero, which is what the display can express
    and what a timer should do.
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2026-09-03 Stop the clock from jumping 49 days when two tasks collide
    The wall read KLOCKAN ÄR TJUGO I FYRA on a September morning. It was not stuck.
    It was running at exactly the right rate -- 120,0 s per 120,1 s of real time --
    99 days 10:05:34 ahead, rendering 15:40. A 12-hour word clock cannot tell 03:40
    from 15:40, so a wrong clock reads exactly like a frozen one.
    The offset was 8 589 934 s: exactly two 32-bit millisecond wraps, measured twice
    and stable to 0,05 s. Nothing had set it there. Uptime was 10,2 h against WLED's
    11,67 h sync interval, so no NTP sync had run since boot; fs.pmt was 0, so
    setTimeFromAPI had never fired; /json/nodes was empty, so no UDP peer; and a raw
    SNTP probe showed t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
2026-10-06 Box in the back plate with a rim and slot the shell walls for wiring
    [1_topshell-SVART.stl, 3_bakplatta-SVART.stl]
